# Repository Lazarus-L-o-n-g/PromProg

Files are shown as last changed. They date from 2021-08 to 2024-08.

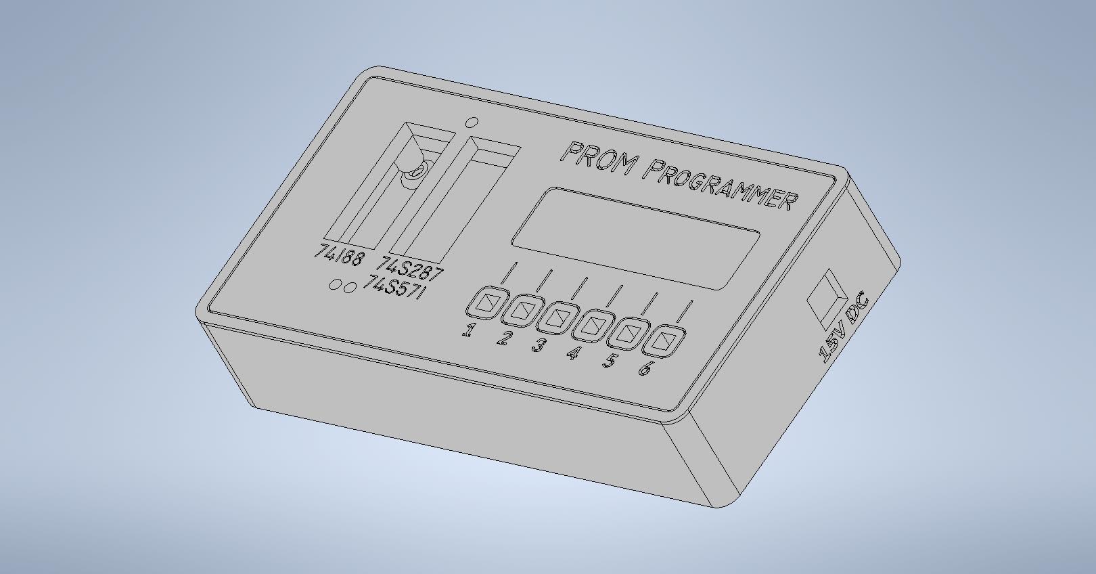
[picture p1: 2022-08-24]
STL/Design_by_72ka/PromProg_case_by_72ka.jpg

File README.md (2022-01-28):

# PromProg


PromProg is a versatile PROM Programmer for three basic PROM chips - 74188, 74S287 and 74S571.
Device is based on ATmega16 microcontroller, data for programming can be downloaded from master computer from your preferred terminal software in Intel HEX format or entered manually using keyboard. You can also read the content from chip and send it to the computer.

For powering use 15V/1A wall adapter or bench power supply.

More info at https://www.8bit-replicas.com/index.php/2021/08/26/programator-pamati-prom/

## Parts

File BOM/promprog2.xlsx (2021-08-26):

Designator | Package | Quantity | Designation | Supplier and reference
 |  |  |  | SOS | TME | Mouser
C1 | CP_Elec_10x10 | 1 | 1000uF/10V | 69611 (https://www.sos.sk/products/samwha/sc-1000uf-10v-85degc-sc1a108m10010vr259-69611) | EEEFC1A102AP (https://www.tme.eu/sk/details/eeefc1a102ap/elektrolyticke-kondenzatory-smd-105degc/panasonic/) | 647-UUR1A102MNL1GS (https://www.mouser.sk/ProductDetail/Nichicon/UUR1A102MNL1GS?qs=SYXD2GzKOolviumaL2ylwA%3D%3D)
C2 | CP_EIA-3216-18_Kemet-A | 1 | 22uF/6.3V |  | TAJA226K010R (https://www.tme.eu/sk/details/taja226k010r/tantalove-kondenzatory-smd/avx/taja226k010rnj/) | 581-TAJA226K006RNJV (https://www.mouser.sk/ProductDetail/AVX/TAJA226K006RNJV)
C3, C5, C6, C7, C8, C10, C13 | C_1206_3216Metric_Pad1.24x1.80mm_HandSolder | 7 | 100nF | 36996 (https://www.sos.sk/products/yageo/k1206-0-1uf-x7r-50v-10-cc1206krx7r9bb104-2-36996) | 1206B104K500CT (https://www.tme.eu/sk/details/1206b104k500ct/kondenzatory-mlcc-smd-1206/walsin/) | 80-C1206C104M5R (https://www.mouser.sk/ProductDetail/KEMET/C1206C104M5RACTU?qs=2BArZ0I3QllzEBgqgvztlA%3D%3D)
C4 | CP_Elec_8x10 | 1 | 470uF/16V | 69618 (https://www.sos.sk/products/samwha/sc-470uf-16v-85degc-sc1c477m08010vr259-69618) | EEEFT1E471AP (https://www.tme.eu/sk/details/eeeft1e471ap/elektrol-kondenzatory-smd-s-nizkou-imp/panasonic/) | 80-EDH477M016A9MAA (https://www.mouser.sk/ProductDetail/KEMET/EDH477M016A9MAA?qs=E9QF1UCAUX4muXx5P8Bksw%3D%3D)
C9 | C_1206_3216Metric_Pad1.24x1.80mm_HandSolder | 1 | 10nF | 36984 (https://www.sos.sk/products/yageo/k1206-0-01uf-x7r-50v-10-cc1206krx7r9bb103-2-36984) | CC1206KRX7R9103 (https://www.tme.eu/sk/details/cc1206krx7r9103/kondenzatory-mlcc-smd-1206/yageo/cc1206krx7r9bb103/) | 710-885012208112 (https://www.mouser.sk/ProductDetail/Wurth-Elektronik/885012208112?qs=MLItCLRbWsy%2FYdqOcuhH5A%3D%3D)
C11, C12 | C_1206_3216Metric_Pad1.24x1.80mm_HandSolder | 2 | 22p | 36892 (https://www.sos.sk/products/yageo/k1206-22pf-np0-50v-5-cc1206jrnpo9bn220-2-36892) | 1206N220K102CT (https://www.tme.eu/sk/details/1206n220k102ct/kondenzatory-mlcc-smd-1206/walsin/) | 710-885012008011 (https://www.mouser.sk/ProductDetail/Wurth-Elektronik/885012008011?qs=0KOYDY2FL28AsR4yyP%252Bdlg%3D%3D)
D1 | D_SMB_Handsoldering | 1 | S2B | 45860 (https://www.sos.sk/products/diotec/s2b-2-45860) | S2B-DC (https://www.tme.eu/sk/details/s2b-dc/univerzalne-diody-smd/dc-components/s2b/) | 621-S2B-F (https://www.mouser.sk/ProductDetail/Diodes-Incorporated/S2B-13-F?qs=To9KJ6x%252BKnNzWwdO0ekNBw%3D%3D)
D2, D3, D4 | D_SMA_Handsoldering | 3 | SK310SMA | 53638 (https://www.sos.sk/products/diotec/sk310-sma-53638) | SK110-DIO (https://www.tme.eu/sk/details/sk110-dio/diody-schottky-smd/diotec-semiconductor/sk110/) | 833-SK110-TP (https://www.mouser.sk/ProductDetail/Micro-Commercial-Components-MCC/SK110-TP?qs=supzuu2Wcq5TaVZ6skmBWg%3D%3D)
D5, D6 | LED_D3.0mm | 2 | LED Red | 12330 (https://www.sos.sk/products/kingbright/l-934-id-12330) | L-34ID (https://www.tme.eu/sk/details/l-34id/led-diody-tht-3mm/kingbright-electronic/) | 604-WP132XIT (https://www.mouser.sk/ProductDetail/Kingbright/WP132XIT?qs=1bZVL%2F32H8H4XBMEQHm3BA%3D%3D)
D7 | LED_D3.0mm | 1 | LED Green | 12389 (https://www.sos.sk/products/kingbright/l-934-gd-12389) | L-34GD (https://www.tme.eu/sk/details/l-34gd/led-diody-tht-3mm/kingbright-electronic/) | 604-WP132XGD (https://www.mouser.sk/ProductDetail/Kingbright/WP132XGD?qs=sGAEpiMZZMuCm2JlHBGefv33PoQKhhXZ1zzzPh7XiAI%3D)
DS1 | WC1602A | 1 | LCD16X2 | 52951 (https://www.sos.sk/products/bolymin/bc-1602a-ypleh-1-52951) | RC1602B-BIW-ESX (https://www.tme.eu/sk/details/rc1602b-biw-esx/alfanumericke-lcd-displeje/raystar-optronics/) | 668-NMCS1625DYHSAY22 (https://www.mouser.sk/ProductDetail/Microtips-Technology/NMTC-S16205DFYHSAY-22?qs=lYGu3FyN48fOaEFjlEoFmw%3D%3D) | najlacnejsi dostupny displej, kazdy nech si da podla vlastneho vkusu
DS1* | PinHeader_1x16_P2.54mm_Vertical | 1 |  | 55112 (https://www.sos.sk/products/various/wws-40-g-sl40g1-55112) | ZL201-16G (https://www.tme.eu/sk/details/zl201-16g/konektory-hrebienky/connfly/ds1021-1-16sf11/) | 649-1012937891603BLF (https://www.mouser.sk/ProductDetail/Amphenol-FCI/10129378-916003BLF?qs=0lQeLiL1qyYNgl1NJHCHgA%3D%3D)
DS1** | PinSocket_1x16_P2.54mm_Vertical | 1 |  | 2181 (https://www.sos.sk/products/fischer-elektronik/bl-1-30-z-1-2181) | ZL262-16SG (https://www.tme.eu/sk/details/zl262-16sg/konektory-hrebienky/connfly/ds1023-1-16s21/) | 437-8018301610001101 (https://www.mouser.sk/ProductDetail/Preci-dip/801-83-016-10-001101?qs=FtMuP6KVi2QJ4M3RBaRPJQ%3D%3D)
DS1*** | Hex standoff | 4 | M3/12mm | 8362 (https://www.sos.sk/products/various/di5-m3x12-8362) | TFF-M3X12/DR114 (https://www.tme.eu/sk/details/tff-m3x12_dr114/distancne-prvky-kovove/dremec/114x12/) | 534-24394 (https://www.mouser.sk/ProductDetail/Keystone-Electronics/24394?qs=UWqYQ%2F2cZWsm%252BXrm2u%2FEww%3D%3D)
J1 | BarrelJack_Horizontal | 1 | HEBA21 | 49926 (https://www.sos.sk/products/various/heba-21-49926) | NEB21R (https://www.tme.eu/sk/details/neb21r/konektory-dc/lumberg/neb-21-r/) | 992-CON-SOCJ-2155 (https://www.mouser.sk/ProductDetail/Gravitech/CON-SOCJ-2155?qs=fkzBJ5HM%252BdCcpvFQyQZHtA%3D%3D)
J2 | PinHeader_2x03_P2.54mm_Vertical | 1 | AVR-ISP-6 | 25332 (https://www.sos.sk/products/various/wwd-16-g-1-25332) | ZL202-6G (https://www.tme.eu/sk/details/zl202-6g/konektory-hrebienky/connfly/ds1021-2-3sf1-1/)
J3 | USB_Mini-B_Lumber_2486_Horizontal | 1 | USB_B_Mini | 49058 (https://www.sos.sk/products/various/usb-bum5-smd-a-usbb-m5-smd-c-49058) | 10033526-N3212MLF/ (https://www.tme.eu/sk/details/10033526-n3212mlf_/konektory-usb-a-ieee1394/amphenol-icc/10033526-n3212mlf/) | 640-2665RBHM15STB01A (https://www.mouser.sk/ProductDetail/GCT/USB2066-05-RBHM-15-STB-00-01-A?qs=KUoIvG%2F9IlbKAciKgzxqOg%3D%3D)
J5, J8 | PinSocket_1x04_P2.54mm_Vertical | 2 | 4Pin F Header |  | ZL262-4SG (https://www.tme.eu/sk/details/zl262-4sg/konektory-hrebienky/connfly/ds1023-1-4s21/) | 437-3108710401640101 (https://www.mouser.sk/ProductDetail/Preci-dip/310-87-104-01-640101?qs=j%2F3uP2fRwpkCY8Ks9fHx2Q%3D%3D)
J6, J7 | PinHeader_1x04_P2.54mm_Vertical | 2 | 4Pin Header |  | ZL201-04G (https://www.tme.eu/sk/details/zl201-04g/konektory-hrebienky/connfly/ds1021-1-4sf1-1/) | 649-1012937890402BLF (https://www.mouser.sk/ProductDetail/Amphenol-FCI/10129378-904002BLF?qs=0lQeLiL1qyaw2kaC5TTjqQ%3D%3D)
Q1 | TO-252-3_TabPin2 | 1 | IRFR9024 | 6959 (https://www.sos.sk/products/vishay-ir/irfr-9024-pbf-6959) | IRFR9024NTRPBF (https://www.tme.eu/sk/details/irfr9024ntrpbf/tranzistory-s-kanalom-p-smd/infineon-technologies/) | 942-IRFR9024NTRPBF (https://www.mouser.sk/ProductDetail/Infineon-IR/IRFR9024NTRPBF?qs=Z8%252BeY1k3TIJekAbEhgu%252Bew%3D%3D)
Q2, Q4, Q5, Q6, Q7, Q8, Q9, Q10 | SOT-223-3_TabPin2 | 8 | BCP51 |  | BCP5116TA (https://www.tme.eu/sk/details/bcp5116ta/tranzistory-pnp-smd/diodes-incorporated/) | 771-BCP51-10135 (https://www.mouser.sk/ProductDetail/Nexperia/BCP51-10135?qs=me8TqzrmIYUWkEJpK6cpZw%3D%3D)
Q3 | SOT-23_Handsoldering | 1 | BC847 | 294795 (https://www.sos.sk/products/diotec/bc847b-1-294795) | BC847B-TP (https://www.tme.eu/sk/details/bc847b-tp/tranzistory-npn-smd/micro-commercial-components/) | 771-BC847B235 (https://www.mouser.sk/ProductDetail/Nexperia/BC847B235?qs=me8TqzrmIYU7qZUbAZqgQg%3D%3D)
R1, R2, R3, R4, R5, R6, R7, R8, R24, R25, R26, R27, R28, R29 | R_1206_3216Metric_Pad1.24x1.80mm_HandSolder | 14 | 10k | 34472 (https://www.sos.sk/products/yageo/r1206-1-10-k-rc1206fr-0710kl-1-34472) | SMD1206-10K (https://www.tme.eu/sk/details/smd1206-10k/rezistory-smd-1206/royal-ohm/1206s4j0103t5e/) | 603-RC1206JR-0710KL (https://www.mouser.sk/ProductDetail/YAGEO/RC1206JR-0710KL)
R9 | R_1206_3216Metric_Pad1.24x1.80mm_HandSolder | 1 | 330R | 35063 (https://www.sos.sk/products/yageo/r1206-1-330-r-rc1206fr-07330rl-2-35063) | SMD1206-330R (https://www.tme.eu/sk/details/smd1206-330r/rezistory-smd-1206/royal-ohm/1206s4j0331t5e/) | 603-RC1206JR-07330RL (https://www.mouser.sk/ProductDetail/YAGEO/RC1206JR-07330RL)
R10 | R_1206_3216Metric_Pad1.24x1.80mm_HandSolder | 1 | 3k0 |  | SMD1206-3K (https://www.tme.eu/sk/details/smd1206-3k/rezistory-smd-1206/royal-ohm/1206s4j0302t5e/) | 603-AC1206JR-073KL (https://www.mouser.sk/ProductDetail/YAGEO/AC1206JR-073KL)
R11 | R_1206_3216Metric_Pad1.24x1.80mm_HandSolder | 1 | 33k | 35099 (https://www.sos.sk/products/yageo/r1206-1-33-k-rc1206fr-0733kl-1-35099) | SMD1206-33K (https://www.tme.eu/sk/details/smd1206-33k/rezistory-smd-1206/royal-ohm/1206s4j0333t5e/) | 652-CR1206-JW-333ELF (https://www.mouser.sk/ProductDetail/Bourns/CR1206-JW-333ELF)
R12, R13, R14, R15, R16, R18, R19, R20, R21, R22, R23, R31, R32, R33, R34 | R_1206_3216Metric_Pad1.24x1.80mm_HandSolder | 15 | 1k | 34376 (https://www.sos.sk/products/yageo/r1206-1-1-k-rc1206fr-071kl-1-34376) | SMD1206-1K (https://www.tme.eu/sk/details/smd1206-1k/rezistory-smd-1206/royal-ohm/1206s4j0102t5e/) | 652-CR1206-JW-102ELF (https://www.mouser.sk/ProductDetail/Bourns/CR1206-JW-102ELF)
R17 | R_1206_3216Metric_Pad1.24x1.80mm_HandSolder | 1 | 100k | 34579 (https://www.sos.sk/products/yageo/r1206-1-100-k-rc1206fr-07100kl-1-34579) | SMD1206-100K (https://www.tme.eu/sk/details/smd1206-100k/rezistory-smd-1206/royal-ohm/1206s4j0104t5e/) | 652-CR1206JW-104ELF (https://www.mouser.sk/ProductDetail/Bourns/CR1206-JW-104ELF)
R30 | R_1206_3216Metric_Pad1.24x1.80mm_HandSolder | 1 | 10R | 33952 (https://www.sos.sk/products/yageo/r1206-1-10-r-rc1206fr-0710rl-2-33952) | SMD1206-10R (https://www.tme.eu/sk/details/smd1206-10r/rezistory-smd-1206/royal-ohm/1206s4j0100t5e/) | 652-CR1206-JW-100ELF (https://www.mouser.sk/ProductDetail/Bourns/CR1206-JW-100ELF)
R35, R36 | R_1206_3216Metric_Pad1.24x1.80mm_HandSolder | 2 | 68R | 35053 (https://www.sos.sk/products/yageo/r1206-1-68-r-rc1206fr-0768rl-2-35053) | SMD1206-68R (https://www.tme.eu/sk/details/smd1206-68r/rezistory-smd-1206/royal-ohm/1206s4j0680t5e/) | 603-RC1206JR-0768RL (https://www.mouser.sk/ProductDetail/YAGEO/RC1206JR-0768RL)
RV1 | Bourns_3364W | 1 | 20k |  | 3364X-1-203E (https://www.tme.eu/sk/details/3364x-1-203e/potenciometre-jednootackove-smd/bourns/) |  | 3364W je uz Obsolette, nahrada 3364X
SW1, SW2, SW3, SW4, SW5, SW6 | SW_PUSH_6mm | 6 | B3F-1052 | 42620 (https://www.sos.sk/products/omron/b3f-1052-42620) | B3F-1052 (https://www.tme.eu/sk/details/b3f-1052/mikrospinace-tact/omron-ocb/) | 653-B3F-1052 (https://www.mouser.sk/ProductDetail/Omron-Electronics/B3F-1052)
SW1*, SW2*, SW3*, SW4*, SW5*, SW6* | Keycaps Black | 4 | B32-1010 | 53256 (https://www.sos.sk/products/omron/b32-1010-53256) | B32-1010 (https://www.tme.eu/sk/details/b32-1010/mikrospinace-tact/omron-ocb/) | 653-B32-1010 (https://www.mouser.sk/ProductDetail/Omron-Electronics/B32-1010)
SW5* | Keycap Green | 1 | B32-1070 |  | B32-1070 (https://www.tme.eu/sk/details/b32-1070/mikrospinace-tact/omron-ocb/) | 653-B32-1070 (https://www.mouser.sk/ProductDetail/Omron-Electronics/B32-1070)
SW6* | Keycap Red | 1 | B32-1080 |  | B32-1080 (https://www.tme.eu/sk/details/b32-1080/mikrospinace-tact/omron-ocb/) | 653-B32-1080 (https://www.mouser.sk/ProductDetail/Omron-Electronics/B32-1080)
U1 | DCDC_Small | 1 | MENIC_DC-DC_MINI |  |  |  | e-bay/Aliexpress (https://www.ebay.com/itm/143585320117?hash=item216e5a1cb5:g:erAAAOSwkA5enUMr) | da sa pouzit aj tento, len ma inak zapojene vyvody, treba predratovat (https://techfun.sk/produkt/dc-dc-step-down-modul-3a-mp1584/)
U2 | TO-263-3_TabPin2 | 1 | LM317D2TG |  | LM317D2TG (https://www.tme.eu/sk/details/lm317d2tg/stabilizatory-napatia-regulovane/on-semiconductor/) | 863-LM317D2TG (https://www.mouser.sk/ProductDetail/onsemi/LM317D2TG)
U3, U6 | DIP-16_W7.62mm_LongPads | 2 | ZIF 16 pin |  | DS1044-160G (https://www.tme.eu/sk/details/ds1044-160g/testovacie-patice/connfly/)
U3*, U6* | DIP-16 precizna patica | 2 |  |  | GOLD-16P (https://www.tme.eu/sk/details/gold-16p/presne-patice/connfly/ds1001-01-16bt1nsf6s/) | 575-1104731641001000 (https://www.mouser.sk/ProductDetail/Mill-Max/110-47-316-41-001000?qs=5aG0NVq1C4yoqQrdVGL0iA%3D%3D) | k montazi su zapotreby aj 4x8pin kolikova lista standardna a 4x8pin kolikova lista precizna
U3**, U6** | PinHeader_1x08_P2.54mm_Vertical_Round | 4 |  |  | STS-20P-K (https://www.tme.eu/sk/details/sts-20p-k/konektory-hrebienky/connfly/ds1004-1x20f1-2/)
U3***, U6*** | PinHeader_1x08_P2.54mm_Vertical | 4 |  |  | ZL201-08G (https://www.tme.eu/sk/details/zl201-08g/konektory-hrebienky/connfly/ds1021-1-8sf1-1/)
U4 | SOIC-16_3.9x9.9mm_P1.27mm | 1 | 74LS595 | 2807 (https://www.sos.sk/products/on-semiconductor/74-hc-595-ad-2807) | 74HCT595D.112 (https://www.tme.eu/sk/details/74hct595d.112/posuvne-registre/nexperia/) | 621-74HCT595S16-13 (https://www.mouser.sk/ProductDetail/Diodes-Incorporated/74HCT595S16-13?qs=Oxncjon6mbpgzt%2FDZvS0qg%3D%3D)
U7 | SOIC-16_3.9x9.9mm_P1.27mm | 1 | 74LS138 |  | 74HCT138D.652 (https://www.tme.eu/sk/details/74hct138d.652/dekodery-multiplexory-spinace/nexperia/) | 771-74HCT138D-T (https://www.mouser.sk/ProductDetail/Nexperia/74HCT138D653)
U8 | TQFP-44_10x10mm_P0.8mm | 1 | ATMEGA16-16AU | 184076 (https://www.sos.sk/products/microchip/atmega16a-aur-184076) | ATMEGA16A-AU (https://www.tme.eu/sk/details/atmega16a-au/modelovy-rad-avr-8-bit/microchip-atmel/) | 556-ATMEGA16A-AU (https://www.mouser.sk/ProductDetail/Microchip-Technology-Atmel/ATMEGA16A-AU?qs=6WoM%2FY8vMbZ9wexLWrnSLQ%3D%3D)
U9 | SOIC-16_3.9x9.9mm_P1.27mm | 1 | CH340G |  |  |  | e-bay/Aliexpress (https://www.ebay.com/itm/142673030818?hash=item2137f9aea2:g:Z30AAOSwvTpZ5tU-)
U10 | SOIC-16_3.9x9.9mm_P1.27mm | 1 | 74LS165 | 24033 (https://www.sos.sk/products/various/74-hc-165-m1-24033) | CD74HCT165M (https://www.tme.eu/sk/details/cd74hct165m/posuvne-registre/texas-instruments/) | 771-74HCT165D-T (https://www.mouser.sk/ProductDetail/Nexperia/74HCT165D653)
Y1 | Crystal_SMD_HC49-SD_HandSoldering | 1 | 12MHz |  | 12M-49SMD-SR (https://www.tme.eu/sk/details/12m-49smd-sr/krystalove-rezonatory-smd/sr-passives/) | 717-9C-12.000MBBK-T (https://www.mouser.sk/ProductDetail/TXC-Corporation/9C-12000MBBK-T?qs=hYDWXTGfSglj%252B27S0dxvgg%3D%3D)

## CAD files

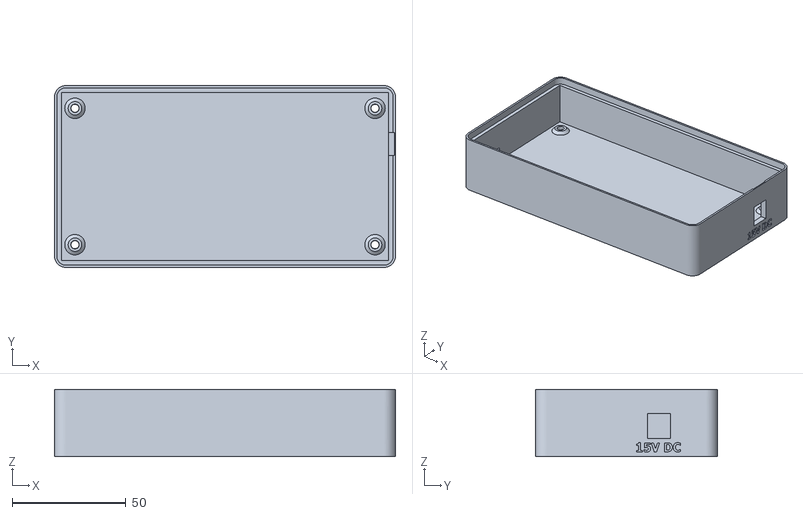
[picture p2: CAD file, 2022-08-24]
STL/Design_by_72ka/bottom.stl
150.0 x 80.0 x 29.5

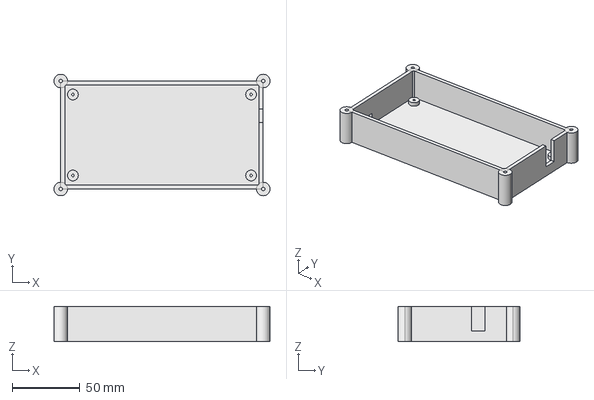
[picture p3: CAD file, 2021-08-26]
STL/Original_design/bottom.fcstd
160.0 x 90.0 x 26.0 mm

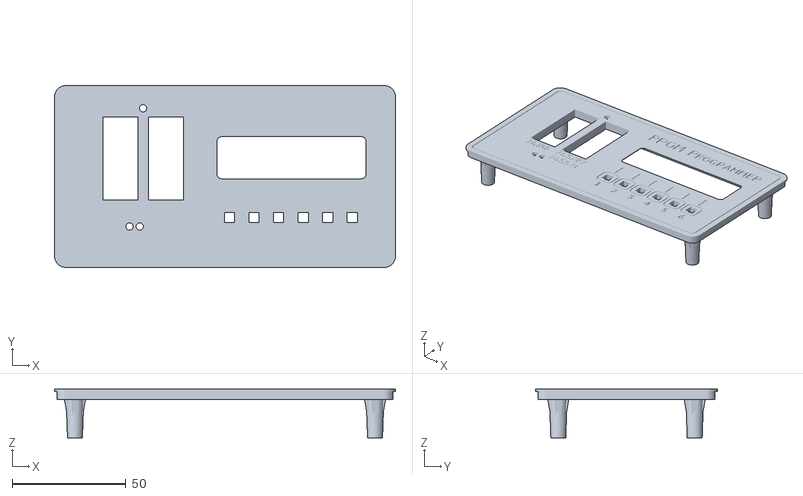
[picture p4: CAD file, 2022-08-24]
STL/Design_by_72ka/top.stl
150.0 x 80.0 x 21.5

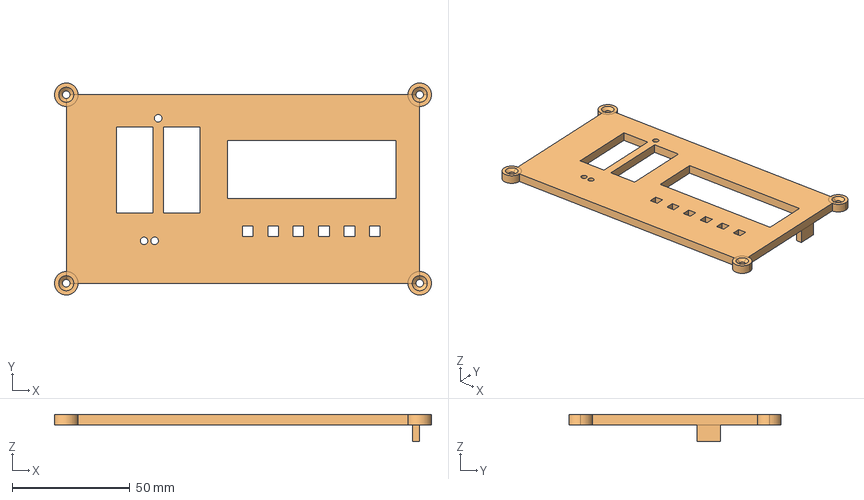
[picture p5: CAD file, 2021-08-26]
STL/Original_design/top.fcstd
160.0 x 90.0 x 11.5 mm

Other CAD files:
Software/promprog.obj
STL/Design_by_72ka/PromProg_case.iam
STL/Design_by_72ka/bottom.ipt
STL/Design_by_72ka/top.ipt
STL/Original_design/bottom.stl
STL/Original_design/top.stl

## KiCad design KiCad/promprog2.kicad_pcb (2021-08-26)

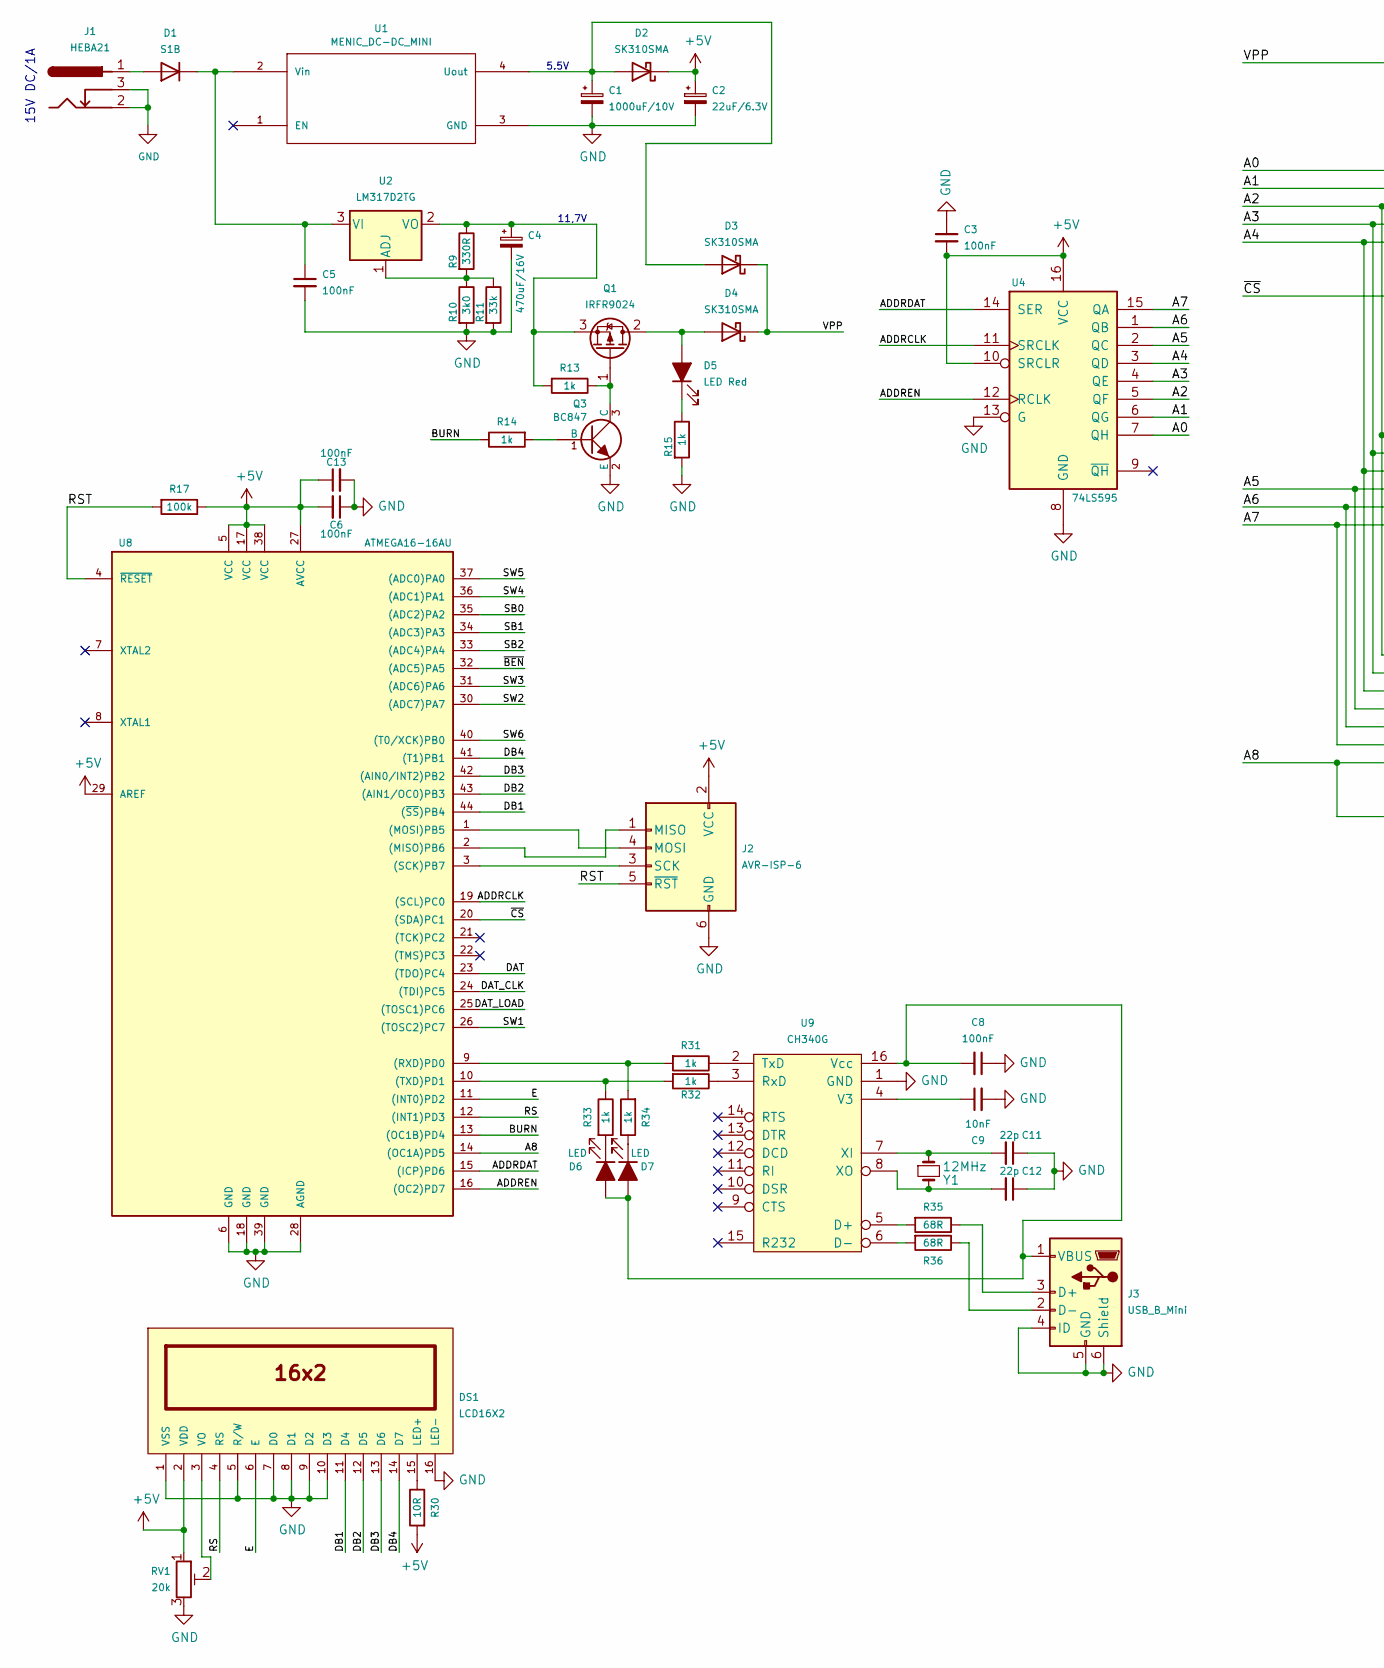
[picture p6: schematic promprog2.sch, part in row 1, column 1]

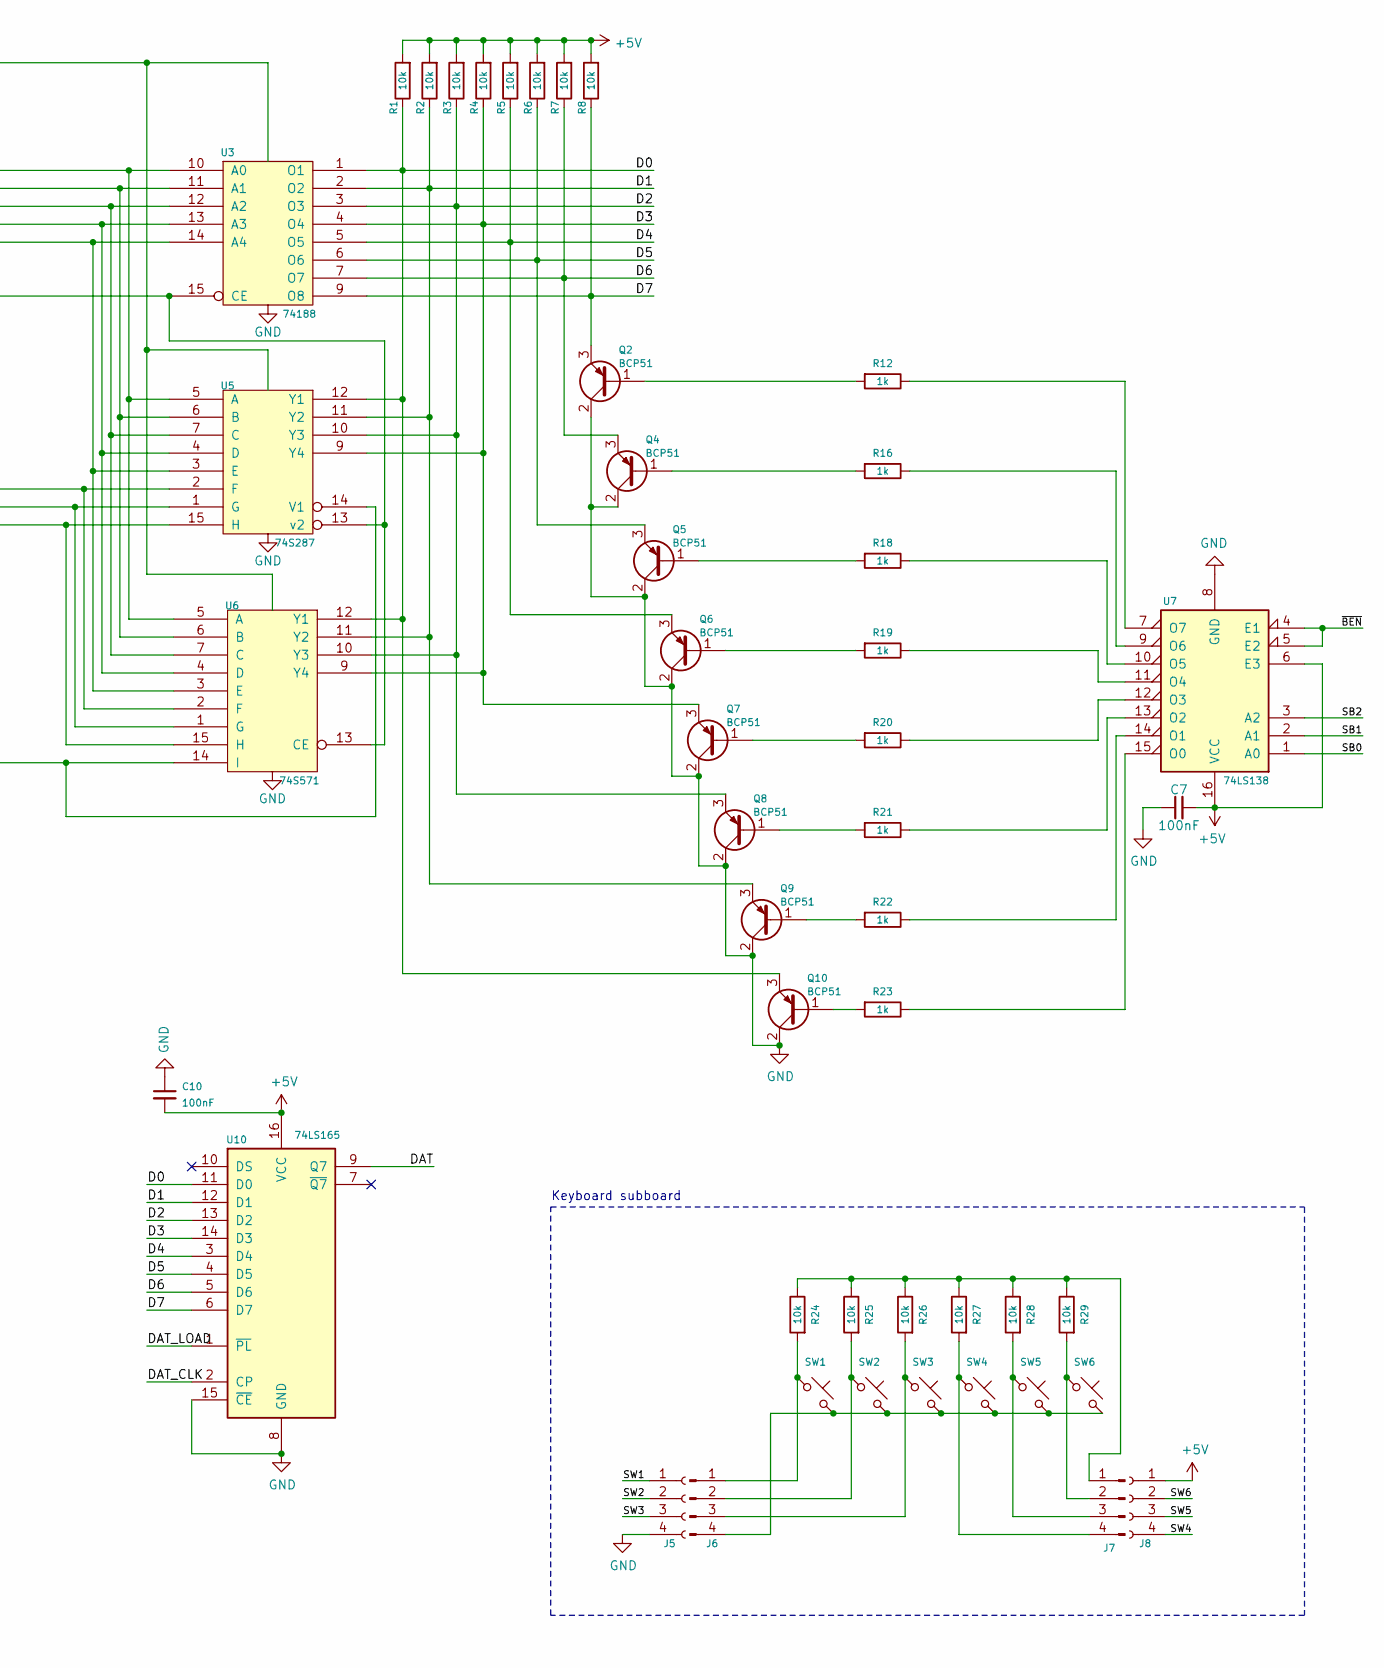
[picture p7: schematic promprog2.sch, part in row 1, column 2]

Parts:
C1: 1000uF/10V; CP_Elec_10x10
C2: 22uF/6.3V; CP_EIA-3216-18_Kemet-A
C3, C5, C6, C7, C8, C10, C13: 100nF; C_1206_3216Metric_Pad1.24x1.80mm_HandSolder
C4: 470uF/16V; CP_Elec_8x10
C9: 10nF; C_1206_3216Metric_Pad1.24x1.80mm_HandSolder
C11, C12: 22p; C_1206_3216Metric_Pad1.24x1.80mm_HandSolder
D1: S1B; D_SMB_Handsoldering
D2, D3, D4: SK310SMA; D_SMA_Handsoldering
D5: LED Red; LED_D3.0mm
D6, D7: LED; LED_D3.0mm
DS1: LCD16X2; WC1602A
J1: HEBA21; BarrelJack_Horizontal
J2: AVR-ISP-6; PinHeader_2x03_P2.54mm_Vertical
J3: USB_B_Mini; USB_Mini-B_Lumber_2486_Horizontal
J5, J8: 4Pin F Header; PinSocket_1x04_P2.54mm_Vertical
J6, J7: 4Pin Header; PinHeader_1x04_P2.54mm_Vertical
Q1: IRFR9024; TO-252-3_TabPin2
Q2, Q4, Q5, Q6, Q7, Q8, Q9, Q10: BCP51; SOT-223-3_TabPin2
Q3: BC847; SOT-23_Handsoldering
R1, R2, R3, R4, R5, R6, R7, R8, R24, R25, R26, R27, R28, R29: 10k; R_1206_3216Metric_Pad1.24x1.80mm_HandSolder
R9: 330R; R_1206_3216Metric_Pad1.24x1.80mm_HandSolder
R10: 3k0; R_1206_3216Metric_Pad1.24x1.80mm_HandSolder
R11: 33k; R_1206_3216Metric_Pad1.24x1.80mm_HandSolder
R12, R13, R14, R15, R16, R18, R19, R20, R21, R22, R23, R31, R32, R33, R34: 1k; R_1206_3216Metric_Pad1.24x1.80mm_HandSolder
R17: 100k; R_1206_3216Metric_Pad1.24x1.80mm_HandSolder
R30: 10R; R_1206_3216Metric_Pad1.24x1.80mm_HandSolder
R35, R36: 68R; R_1206_3216Metric_Pad1.24x1.80mm_HandSolder
RV1: 20k; bourns_3364W
SW1, SW2, SW3, SW4, SW5, SW6: B3F-1052; SW_PUSH_6mm
U1: MENIC_DC-DC_MINI; DCDC_Small
U2: LM317D2TG; TO-263-3_TabPin2
U3: 74188; DIP-16_W7.62mm_LongPads
U4: 74LS595; SOIC-16_3.9x9.9mm_P1.27mm
U5: 74S287; DIP-16_W7.62mm_LongPads
U6: 74S571; DIP-16_W7.62mm_LongPads
U7: 74LS138; SOIC-16_3.9x9.9mm_P1.27mm
U8: ATMEGA16-16AU; TQFP-44_10x10mm_P0.8mm
U9: CH340G; SOIC-16_3.9x9.9mm_P1.27mm
U10: 74LS165; SOIC-16_3.9x9.9mm_P1.27mm
Y1: 12MHz; Crystal_SMD_HC49-SD_HandSoldering

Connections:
+5V: C2.1, C3.2, C6.2, C7.2, C10.2, C13.1, D2.1 (K), DS1.2 (VDD), J2.2 (VCC), J8.1, R1.2, R2.2, R3.2, R4.2, R5.2, R6.2, R7.2, R8.2, R17.1, R30.2, RV1.1, U4.10 (SRCLR), U4.16 (VCC), U7.6 (E3), U7.16 (VCC), U8.5 (VCC), U8.17 (VCC), U8.27 (AVCC), U8.29 (AREF), U8.38 (VCC), U10.16 (VCC)
/A0: U3.10 (A0), U4.7 (QH), U5.5 (A), U6.5 (A)
/A1: U3.11 (A1), U4.6 (QG), U5.6 (B), U6.6 (B)
/A2: U3.12 (A2), U4.5 (QF), U5.7 (C), U6.7 (C)
/A3: U3.13 (A3), U4.4 (QE), U5.4 (D), U6.4 (D)
/A4: U3.14 (A4), U4.3 (QD), U5.3 (E), U6.3 (E)
/A5: U4.2 (QC), U5.2 (F), U6.2 (F)
/A6: U4.1 (QB), U5.1 (G), U6.1 (G)
/A7: U4.15 (QA), U5.15 (H), U6.15 (H)
/A8: U5.14 (V1), U6.14 (I), U8.14 ((OC1A)PD5)
/ADDRCLK: U4.11 (SRCLK), U8.19 ((SCL)PC0)
/ADDRDAT: U4.14 (SER), U8.15 ((ICP)PD6)
/ADDREN: U4.12 (RCLK), U8.16 ((OC2)PD7)
/BURN: R14.1, U8.13 ((OC1B)PD4)
/D0: Q10.3 (E), R1.1, U3.1 (O1), U5.12 (Y1), U6.12 (Y1), U10.11 (D0)
/D1: Q9.3 (E), R2.1, U3.2 (O2), U5.11 (Y2), U6.11 (Y2), U10.12 (D1)
/D2: Q8.3 (E), R3.1, U3.3 (O3), U5.10 (Y3), U6.10 (Y3), U10.13 (D2)
/D3: Q7.3 (E), R4.1, U3.4 (O4), U5.9 (Y4), U6.9 (Y4), U10.14 (D3)
/D4: Q6.3 (E), R5.1, U3.5 (O5), U10.3 (D4)
/D5: Q5.3 (E), R6.1, U3.6 (O6), U10.4 (D5)
/D6: Q4.3 (E), R7.1, U3.7 (O7), U10.5 (D6)
/D7: Q2.3 (E), R8.1, U3.9 (O8), U10.6 (D7)
/DAT: U8.23 ((TDO)PC4), U10.9 (Q7)
/DAT_CLK: U8.24 ((TDI)PC5), U10.2 (CP)
/DAT_LOAD: U8.25 ((TOSC1)PC6), U10.1 (~PL)
/DB1: DS1.11 (D4), U8.44 ((~SS~)PB4)
/DB2: DS1.12 (D5), U8.43 ((AIN1/OC0)PB3)
/DB3: DS1.13 (D6), U8.42 ((AIN0/INT2)PB2)
/DB4: DS1.14 (D7), U8.41 ((T1)PB1)
/E: DS1.6 (E), U8.11 ((INT0)PD2)
/RS: DS1.4 (RS), U8.12 ((INT1)PD3)
/RST: J2.5 (~RST), R17.2, U8.4 (~RESET)
/SB0: U7.1 (A0), U8.35 ((ADC2)PA2)
/SB1: U7.2 (A1), U8.34 ((ADC3)PA3)
/SB2: U7.3 (A2), U8.33 ((ADC4)PA4)
/SW1: J5.1, U8.26 ((TOSC2)PC7)
/SW2: J5.2, U8.30 ((ADC7)PA7)
/SW3: J5.3, U8.31 ((ADC6)PA6)
/SW4: J8.4, U8.36 ((ADC1)PA1)
/SW5: J8.3, U8.37 ((ADC0)PA0)
/SW6: J8.2, U8.40 ((T0/XCK)PB0)
/VPP: D3.1 (K), D4.1 (K), U3.16 (Vcc), U5.16 (Vcc), U6.16 (Vcc)
/~BEN: U7.4 (E1), U7.5 (E2), U8.32 ((ADC5)PA5)
/~CS: U3.15 (CE), U5.13 (v2), U6.13 (CE), U8.20 ((SDA)PC1)
GND: C1.2, C2.2, C3.1, C4.2, C5.2, C6.1, C7.1, C8.1, C9.2, C10.1, C11.1, C12.1, C13.2, DS1.1 (VSS), DS1.5 (R/W), DS1.7 (D0), DS1.8 (D1), DS1.9 (D2), DS1.10 (D3), DS1.16 (LED-), J1.2, J1.3, J2.6 (GND), J3.4 (ID), J3.5 (GND), J3.6 (Shield), J5.4, Q2.2 (C), Q3.2 (E), Q4.2 (C), Q5.2 (C), Q6.2 (C), Q7.2 (C), Q8.2 (C), Q9.2 (C), Q10.2 (C), R10.2, R11.2, R15.2, RV1.3, U1.3 (GND), U3.8 (GND), U4.8 (GND), U4.13 (G), U5.8 (GND), U6.8 (GND), U7.8 (GND), U8.6 (GND), U8.18 (GND), U8.28 (AGND), U8.39 (GND), U9.1 (GND), U10.8 (GND), U10.15 (~CE)
unnamed: C1.1, D2.2 (A), D3.2 (A), U1.4 (Uout)
unnamed: C4.1, Q1.3 (S), R9.1, R13.2, U2.2 (VO)
unnamed: C5.1, D1.1 (K), U1.2 (Vin), U2.3 (VI)
unnamed: C8.2, D6.2 (A), D7.2 (A), J3.1 (VBUS), U9.16 (Vcc)
unnamed: C9.1, U9.4 (V3)
unnamed: C11.2, U9.7 (XI), Y1.1
unnamed: C12.2, U9.8 (XO), Y1.2
unnamed: D1.2 (A), J1.1
unnamed: D4.2 (A), D5.2 (A), Q1.2 (D)
unnamed: D5.1 (K), R15.1
unnamed: D6.1 (K), R33.2
unnamed: D7.1 (K), R34.1
unnamed: DS1.3 (VO), RV1.2
unnamed: DS1.15 (LED+), R30.1
unnamed: J2.1 (MISO), U8.2 ((MISO)PB6)
unnamed: J2.3 (SCK), U8.3 ((SCK)PB7)
unnamed: J2.4 (MOSI), U8.1 ((MOSI)PB5)
unnamed: J3.2 (D-), R36.1
unnamed: J3.3 (D+), R35.1
unnamed: J6.1, R24.2, SW1.1
unnamed: J6.2, R25.2, SW2.1
unnamed: J6.3, R26.2, SW3.1
unnamed: J6.4, SW1.2, SW2.2, SW3.2, SW4.2, SW5.2, SW6.2
unnamed: J7.1, R24.1, R25.1, R26.1, R27.1, R28.1, R29.1
unnamed: J7.2, R29.2, SW6.1
unnamed: J7.3, R28.2, SW5.1
unnamed: J7.4, R27.2, SW4.1
unnamed: Q1.1 (G), Q3.3 (C), R13.1
unnamed: Q2.1 (B), R12.2
unnamed: Q3.1 (B), R14.2
unnamed: Q4.1 (B), R16.2
unnamed: Q5.1 (B), R18.2
unnamed: Q6.1 (B), R19.2
unnamed: Q7.1 (B), R20.2
unnamed: Q8.1 (B), R21.2
unnamed: Q9.1 (B), R22.2
unnamed: Q10.1 (B), R23.2
unnamed: R9.2, R10.1, R11.1, U2.1 (ADJ)
unnamed: R12.1, U7.7 (O7)
unnamed: R16.1, U7.9 (O6)
unnamed: R18.1, U7.10 (O5)
unnamed: R19.1, U7.11 (O4)
unnamed: R20.1, U7.12 (O3)
unnamed: R21.1, U7.13 (O2)
unnamed: R22.1, U7.14 (O1)
unnamed: R23.1, U7.15 (O0)
unnamed: R31.1, U9.2 (TxD)
unnamed: R31.2, R34.2, U8.9 ((RXD)PD0)
unnamed: R32.1, U9.3 (RxD)
unnamed: R32.2, R33.1, U8.10 ((TXD)PD1)
unnamed: R35.2, U9.5 (D+)
unnamed: R36.2, U9.6 (D-)

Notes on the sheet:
15V DC/1A
11,7V
5.5V
Keyboard subboard

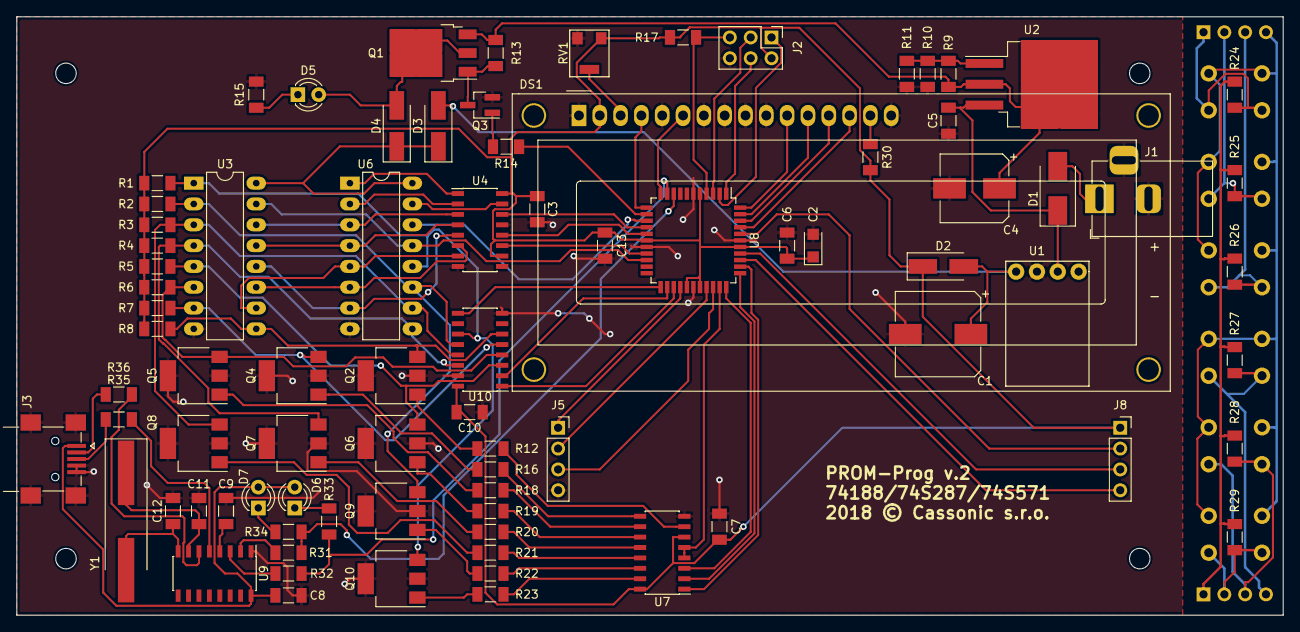
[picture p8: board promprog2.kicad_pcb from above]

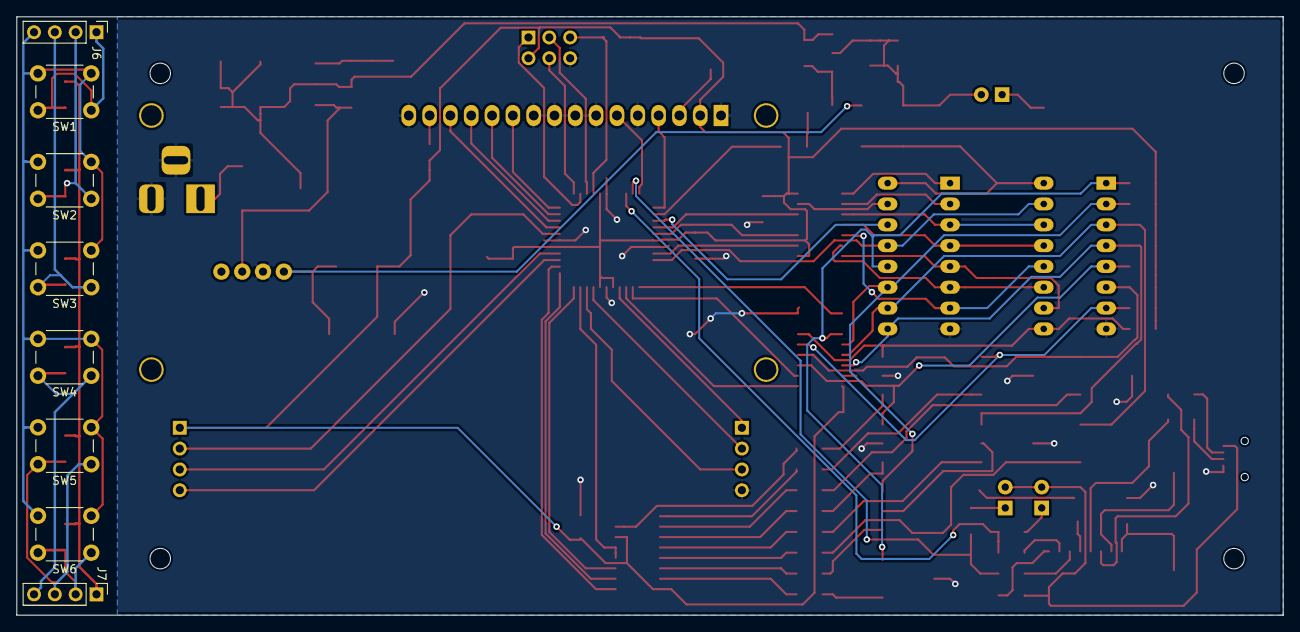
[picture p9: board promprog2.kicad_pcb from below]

Board: 2 copper layers, 154.5 x 73.0 mm, 95 parts (8 on the bottom side), 97 nets.

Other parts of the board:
H1, H2, H3, H4: MountingHole_2.5mm

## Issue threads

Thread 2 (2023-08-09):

Need help with serial communication or debugging

badrianiulian, 2023-08-09:
Hello!
A while back I tried contacting you regarding a spare board but in the meanwhile me and a few friends managed to order some PCBs.
Now that I finished building your project, I am trying to read data from the board through USB-UART but can't seem to get any consistent data. I set the USB serial terminal to 9600 baud as noticed in the source code and the HEX data received looks a little weird when sending data read from an K155PE3 (74188): 0d0a0d0a0d0a0d followed by 14x16 bytes with 00s and 80s
Another few weird things are that when I try to read the data from the PROM, all 32 locations look like they are filled with 00000000 and also when editing the data (EDT) I get the same result. The PROM has some actual data on it.
Maybe a guide could be useful on how to work with the serial port?
What can I check regarding the 0 filled memory locations problem?
Thanks for your work on this project!
I also checked your other project ... really good work on rebuilding the Mistrum ... I'm also trying to do something similar with some Romanian clones of the ZX Spectrum.

badrianiulian, 2023-10-19:
I'm going to answer my own question.
Silly me, I used a TL866A with ICSP and forgot to set the fuses.

Closed 2024-08-27.

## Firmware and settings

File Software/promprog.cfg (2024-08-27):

[COMPILER-CHIP]
Chip=m161def.dat
XRAM=0
Waitstate=0
XA=0
Stacksize=40
Framesize=32
Sstack=16
[COMPILER-OUTPUT]
Report vars=0
Optimize=0
Binary File=1
Hexadecimal File=1
Report File=1
Debug File=1
Error File=1
ASM File=0
LST File=0
OBJ File=1
SWAP File=0
[COMPILER-COMMUNICATION]
Baudrate=9600
Frequency=4000000
[COMPILER-I2C]
Scl=0
Sda=0
[COMPILER-LCD]
DB7=PORTB.7
DB6=PORTB.6
DB5=PORTB.5
DB4=PORTB.4
E=PORTB.3
RS=PORTB.2
LCD=1
BUS mode=0
DATA mode=0
LCD address=C000
LCD-RS=8000
[COMPILER-MISC]
Size Warning=0
1wire=PORTB.0
[COMPILER-SPI]
HW SPI=0
SPICLOCK=13
SPISS=13
SPIMOSI=14
SPIMISO=15

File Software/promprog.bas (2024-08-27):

'--------------------------------
' System settings
'--------------------------------
$regfile = "m16def.dat"
$crystal = 8000000
$hwstack = 40
$swstack = 32
$framesize = 32
'$sim

$baud = 9600

Config Lcdpin = Pin , Rs = Portd.3 , E = Portd.2 , Db4 = Portb.4 , Db5 = Portb.3 , Db6 = Portb.2 , Db7 = Portb.1
Config Lcd = 16 * 2

Config Base = 0
Baud = 9600

'--------------------------------
' Input pin's aliases
'--------------------------------
Sw2 Alias Pina.7
Sw3 Alias Pina.6
Sw5 Alias Pina.0
Sw6 Alias Pinb.0
Sw4 Alias Pina.1
Sw1 Alias Pinc.7
Burn Alias Portd.4
Ben Alias Porta.5
Cs Alias Portc.1
A8 Alias Portd.5
Sb0 Alias Porta.2
Sb1 Alias Porta.3
Sb2 Alias Porta.4
Datclk Alias Portc.5
Datload Alias Portc.6
Dat Alias Pinc.4
Addrclk Alias Portc.0
Addren Alias Portd.7
Addrdat Alias Portd.6


'--------------------------------
' Port pin direction settings
'--------------------------------
Ddra = &B00111100
Ddrb = &B10111110
Ddrc = &B01101111
Ddrd = &B11111110

'--------------------------------
' Constants
'--------------------------------
Const Prom74188 = 31
Const Prom74188b = 8
Const Prom74287 = 255
Const Prom74287b = 4
Const Prom74571 = 511
Const Prom74571b = 4

'--------------------------------
' Public variables
'--------------------------------
Dim Content(512) As Byte
Dim Seltype As Byte
Dim Seladdr As Word
Dim Selwide As Byte
Dim Curaddr As Word
Dim Curdata As Byte
Dim Str4 As String * 4
Dim Str8 As String * 8
Dim Selstr As String * 16
Dim I As Byte
Dim Curpos As Byte , Curs As Byte
Dim Bitpos As Byte
Dim Goout As Byte
Dim Goroot As Byte
Dim Errcount As Integer
Dim Okprog As Byte
Dim Intelhex As String * 41

'--------------------------------
' Subroutines and function
'--------------------------------
Declare Sub Flushdata                                       ' clears memory with chip content
Declare Sub Showrecord(byval Torow As Byte)                 ' shows data at current address
Declare Sub Setaddr                                         ' send address to shift register
Declare Sub Exporthex                                       ' send HEX file to PC
Declare Sub Readhex                                         ' read file from PC in HEX format
Declare Sub Readchip                                        ' read data from chip from current address
Declare Sub Setbit(byval Cislo As Byte)                     ' set programmed bit
Declare Function Checkbit(byval I As Byte) As Byte          ' check if bit is programmed or not

'--------------------------------
' Beginning of program
'--------------------------------
Initlcd

'--------------------------------
' Set up pins
'--------------------------------
Reset Burn
Reset Sb0
Reset Sb1
Reset Sb2
Set Ben
Reset Addrdat
Reset Addren
Reset Addrclk
Set Datload
Reset Datclk
Set Cs

'--------------------------------
' Custom LCD characters
'--------------------------------
Deflcdchar 0 , 1 , 3 , 7 , 15 , 7 , 3 , 1 , 32              ' left
Deflcdchar 1 , 16 , 24 , 28 , 30 , 28 , 24 , 16 , 32        ' right
Deflcdchar 2 , 32 , 32 , 31 , 14 , 4 , 32 , 32 , 32         ' up
Deflcdchar 3 , 32 , 32 , 4 , 14 , 31 , 32 , 32 , 32         ' down
Deflcdchar 4 , 1 , 1 , 1 , 5 , 9 , 31 , 8 , 4               ' enter



Enable Interrupts

'--------------------------------
' Set up clear memory
'--------------------------------
Call Flushdata

'--------------------------------
' Welcome message
'--------------------------------
Cls
Cursor Off Noblink
Locate 1 , 1
Lcd "PROM Programmer"
Locate 2 , 7
Lcd "v1.2"
Wait 2
Locate 1 , 1
Lcd "www.github.com  "
Locate 2 , 1
Lcd "/Lazarus-L-o-n-g"
Wait 3
Cls
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

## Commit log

2021-08-26 KiCad Files
    [promprog2.kicad_pcb, promprog2.sch]
2021-08-26 FreeCad and STL files for box
    [bottom.fcstd, bottom.stl, top.fcstd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]
2021-08-26 Gerber files for PCB
    [promprog2-B_Cu.gbl, promprog2-B_Mask.gbs, promprog2-B_SilkS.gbo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]
2021-08-26 Firmware for microcontroller in Bascom
    [promprog.obj]
2021-08-26 BOM added
    [promprog2.xlsx]
2021-08-26 PCB updated
2021-08-26 updated BOM
    [promprog2.xlsx]
2021-11-11 fuses settings added
2022-08-24 New case design
    [PromProg_case.iam, bottom.fcstd, bottom.ipt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]
2024-08-27 Software v1.2
    New version 1.2
    -Modified UI
    -Programming skips yet programmed bits
    -Programming check also the not-burned bits
    -New Verification function (usable as Blank check also)
    -Error counter could be more than 255 errors
    -Value is also in HEX in right corner
    [promprog.cfg, promprog.obj]

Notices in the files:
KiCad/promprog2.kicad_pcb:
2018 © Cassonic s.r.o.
